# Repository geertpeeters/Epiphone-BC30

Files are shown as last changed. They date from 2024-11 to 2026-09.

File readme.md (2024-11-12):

# Epiphone Blues Custom 30 modifications

## A compact guideline

## Version history

| Version Nr | Version Date | Modification |
|---|---|---|
| 1.0.0 | 2020-01-06 | Initial version for external distribution |

Table 1. Version History

# Introduction

## 1. General feature set

- Ampplifier with an "all tube" signal path
- Tube rectifier
- Two distinct channels
- 3 way equalizer
- Overdrive channel mid control
- Independent and interactive EQ mode
- Tube powered and transformer driven reverb
- 30W class AB (pentode) mode
- 15W Class A (triode) mode
- Multiple speaker output jacks (2x4 Ohm, 2x8 Ohm, 1x16 Ohm)
- "Lady Luck" speakers specially designed for this amplifier

## 2. Overall desired improvements

- Overall "harsh" clean and overdriven sounds
- Perceived as "too bright" with lack of bottom end
- Not switchable between clean and overdriven channel without tweaking
  the EQ settings

## 3. Dismantling instructions

To remove the chassis do the following

1.  Remove the mains power cable
2.  Remove the guitar cable from the input
3.  Remove the speaker cable from the output
4.  Remove the reverb RCA cables from the underside of the chassis
5.  Pry off the 4 plastic covers on top of the amp with a small flat
    blade screwdriver
6.  Remove the machine screws with a \#2 phillips screwdriver
7.  Grab the HT and OT and gently pull out while lifting up
8.  Connect one lead of an alligator clip to the chassis, and the other
    end to the common of a multimeter. probe the power tube solder
    joints making sure to leave one hand in your pocket and confirm the
    meter reads 0V

## 4. Affected components

### 4.1. Capacitors

| Component | Identification | Actual Value | Modification | Expected result |
|---|---|---|---|---|
| **C3** | 471/1kV | 470pF/1000V  | Unsolder or cut off | |
| **C4** | 101/1kV | 100pF/1000V  | Unsolder or cut off | |
| **C5** | 471/400V | 470pF/400V | Unsolder or cut off | |
| **C6** | 101/1kV | 100pF/1000V  | Unsolder or cut off | |
| **C10** | 471/1kV | 470pF/1000V  | Unsolder or cut off | |
| **C15** | 22µF/35V | | Replace 2.2µF/35V | |
| **C16** | 471/1kV | 470pF/1000V  | Increase to 680pF : put 220pF in parallel | |

### 4.2. Resistors

| Component | Identification | Modification | Expected result |
|---|---|---|---|
| **R3** | 2.2kΩ/1W | Replace 1kΩ/1W or shunt with 2.2kΩ for 1.1kΩ | |
| **R5** | 1MΩ/1W | Shunt with 820kΩ for 450kΩ | |
| **R6** | 1MΩ/1W | Shunt with 820k for 450kΩ | |
| **R8** | 2.2kΩ/1W | Replace 1kΩ/1W or shunt with 2.2kΩ for 1.1kΩ | |
| **R15** | 2.2kΩ/1W | Replace 1.6kΩ/1W or shunt with 5.6kΩ for 1.58kΩ | |
| **R21** | 2.2kΩ/1W | Replace 1kΩ/1W or shunt with 2.2kΩ for 1.1kΩ | |
| **R23** | 10kΩ/1W | Replace 5.6kΩ/1W or shunt with 12kΩ for 5.45kΩ | |
| **R39** | 220kΩ/1W | Replace 1MΩ linear potentiometer | |
| **R52**\* | 68Ω/25W | Put in between 350V line and PCB. Mount against chassis for cooling | |
| **R53**\* | 68Ω/25W | Put in between 350V line and PCB. Mount against chassis for cooling | |

## 5. Detailed findings

### 5.1. Capacitors

#### 5.1.1. C3

- **Stock value**: 470pF/1000V
- **Action**: unsolder or cut off
- **Affects**: Clean channel
- **Perceived result**:
  - Cuts brightness off
  - Clean channel sounds less treble-y. easier to manage

#### 5.1.2. C4

- **Stock value**: 470pF/1000V
- **Action**: unsolder or cut off
- **Affects**: Clean channel
- **Perceived result**: Cuts brightness off

#### 5.1.3. C5

- **Stock value**: 470pF/400V
- **Action**: unsolder or cut off
- **Affects**: Both channels. Cuts brightness off
- **Perceived result**:

#### 5.1.4. C6

- **Stock value**: 100pF/1000V
- **Action**: unsolder or cut off
- **Affects**: Both channels. Cuts brightness off
- **Perceived result**: Drive channel now sounds more like a fizzy
  distortion rather than a crunchy overdrive

#### 5.1.5. C10

- **Stock value**: 470pF/1000V
- **Action**: unsolder or cut off
- **Affects**: Both channels. Cuts brightness off
- **Perceived result**: lost way too much top end

##### C15

- **Stock value**: 22uF/35V
- **Action**: replace 2.2uF/35V
- **Affects**: overdrive channel
- **Perceived result**: makes the whole amp brighter, less bottom end.

#### 5.1.6. C16

- **Stock value**: 470pF/1000V
- **Action**: increase to 680pF, put capacitor in parallel
- **Affects**:
- **Perceived result**:

### 5.2. Resistors

#### 5.2.1. R3

- **Stock value**: 2.2kΩ/1W
- **Action**: replace 1k/1W
- **Affects**: ?
- **Perceived result**:?

#### 5.2.2. R5

- **Stock value**: 1MΩ/1W
- **Action**: shunt with 820kΩ/1W
- **Affects**: Drive channel
- **Perceived result**:
  - The fundamental pass frequency is halved
  - Potential divider is halved (more signal to next stage)
  - The sound opens up with increased bass but no loss of top end, not
    dark and not harsh

#### 5.2.3. R6

- **Stock value**: 1MΩ/1W
- **Action**: shunt with 820kΩ/1W
- **Affects**: Drive channel
- **Perceived result**:
  - The fundamental pass frequency is halved
  - Potential divider is halved (more signal to next stage)
  - The sound opens up with increased bass but no loss of top end, not
    dark and not harsh

#### 5.2.4. R8

- **Stock value**: 2.2kΩ/1W
- **Action**: replace 1kΩ/1W
- **Affects**: Drive channel
- **Perceived result**: ?

#### 5.2.5. R15

- **Stock value**: 2.2kΩ/1W
- **Action**: replace 1.6kΩ/1W
- **Affects**: Drive channel
- **Perceived result**:
  - Smoother overdrive : affects overdrive channel
  - Lowered gain → ???
  - Distortion is a bit smoother and not so harsh
  - Really mellows out the channel drive
  - The drive is more manageable
  - Is the best sounding, most noticeable among the mods mentioned.
  - Unbelievable difference. That gain boost brought some fire into the
    tone. Gain was nicely saturated & balanced.

#### 5.2.6. R23

- **Stock value**: 10kΩ/1W
- **Action**: replace 5.6kΩ/1W
- **Affects**: ?
- **Perceived result**: ?

#### 5.2.7. R39

- **Stock value**: 220kΩ/1W
- **Action**:
  - Replace by 1MΩ potentiometer
  - Place potentiometer in front panel of the chassis
  - Wire to PCB with shielded signal cable
- **Affects**: Volume control improvement of clean channel
- **Perceived result**:
  - Better control of clean channel volume
  - Clean channel can be cranked up and controlled by master volume knob

#### 5.2.8. R52
- **Stock value**: not existing
- **Action**:
  - Put in between 350V AC lead of transformer and SS2 on the PCB
- **Affects**: Protects against transformer blow-up
- **Perceived result**: None. Increases robustness of amplifier

#### 5.2.9. R53

- **Stock value**: not existing
- **Action**:
  - Put in between 350V AC lead of transformer and SS1 on the PCB
- **Affects**: Protects against transformer blow-up
- **Perceived result**: None. Increases robustness of amplifier

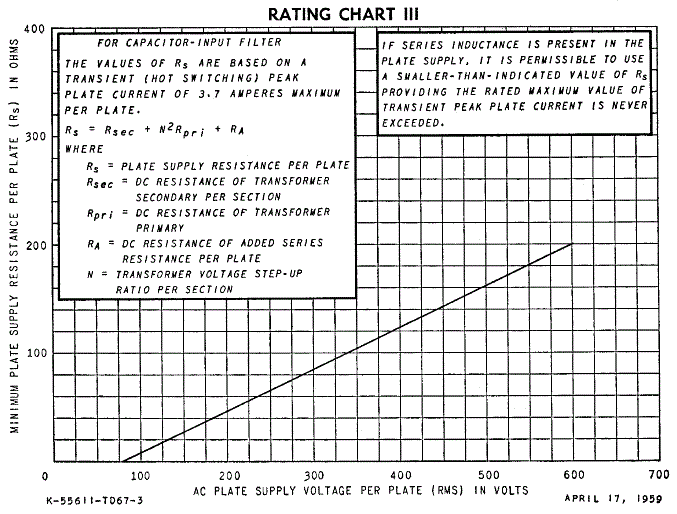
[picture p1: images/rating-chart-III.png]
rating chart III


Figure 1. Limiting resistance calculation graph

It is worth noting that the choke will slightly lower the required
limiting resistance, but not by much. The above datasheet chart provides
the calculation necessary to determine the limiting resistance provided
by the transformer:

Rs = Rsec + N2Rpri

measured Rpri is 5.5R and Rsec is 37.5R (75R for the entire winding) so…
Transformer ratio N = 350 / 240 = 1.45 so…

37.5 + (1.45 \* 1.45 \* 5.5) = 49R

The chart shows that for a 350V tap, the limiting resistance needs to be
around 105R for EACH PLATE of the rectifier, and this is for a fresh
valve manufactured to 1959 standards. So lets assume 115R will be safer
for modern 5AR4s,

115R - 49R = 66R

68R is the nearest standard resistor, two of these should be chassis
mounted inside the amp, and the transformer secondary taps (350V) should
be wired directly to these and then the other ends of the resistors
wired to the PCB. 25W types are recommended, as the voltage rating
should be in the region of 550V. The working voltage in practice will be
much much lower than this but at the moment of power on, it will be
higher and it’s nice to know that nothing can go wrong!

BTW, using the standby switch makes the problem worse because the
rectifier is fully ready to conduct. If you are unlucky enough to flip
the switch at the moment the mains AC voltage is at it’s peak then
destruction is almost guaranteed. Starting the amp from cold (without
the standby) will slightly reduce the likelihood of failure. So, for a
happy BC30, don’t use the standby and install limiting resistors!

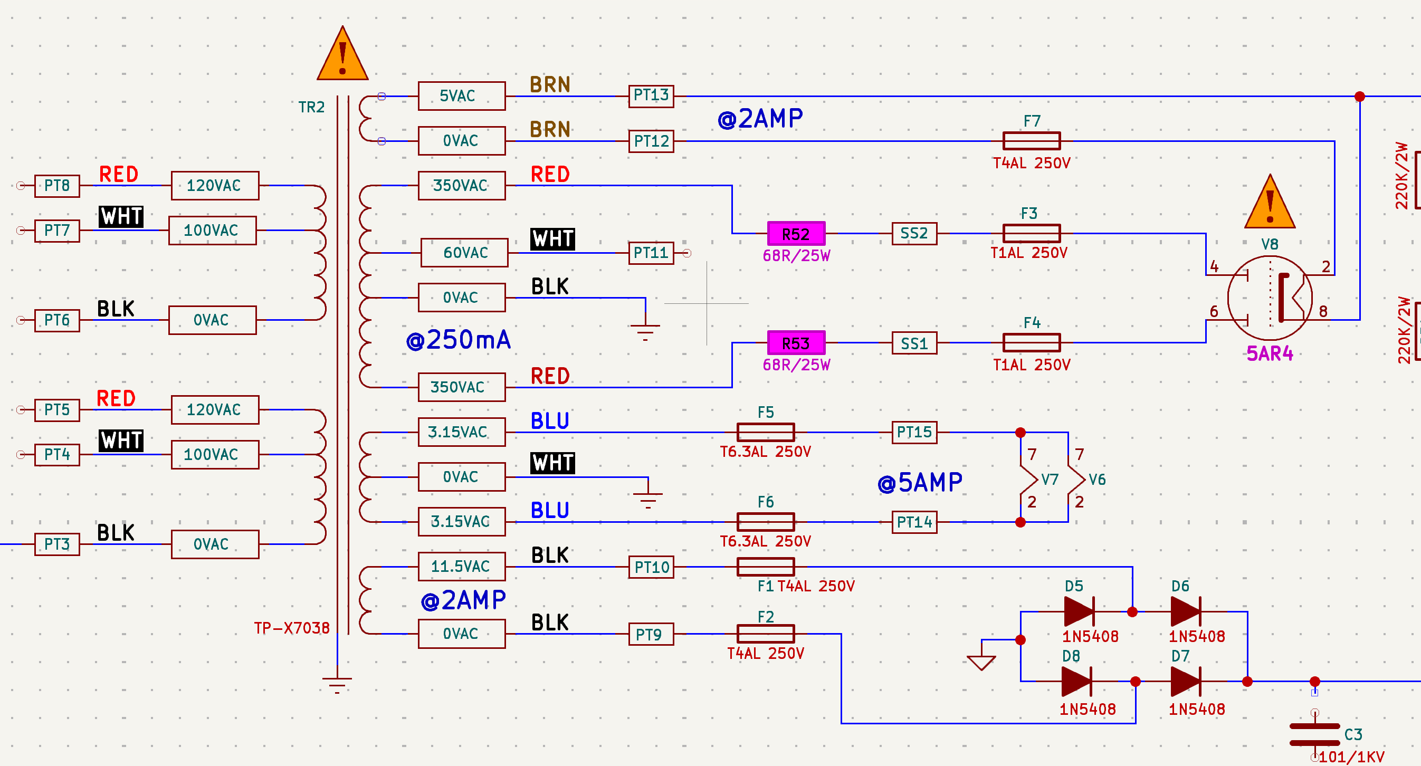
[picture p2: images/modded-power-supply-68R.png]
modded power supply 68R

Figure 2. Limiting resistors of 68Ω

### 5.3. Tried out combinations and their findings

<table>
<td class="content">C5,C6,C10,R15<br />
<strong>This amp is singing now<br />
</strong> Much more manageable/tweak-able</td>
</table>

<table>
<td class="content">C3,C5,C6,R15<br />
In that order you’ll hear the difference</td>
</table>

<table>
<td class="content">C3,C5,C6,C15,R15,R21<br />
<strong>These mods really open this amp up<br />
</strong> EQ is way more definable between active and not<br />
** More use out of the mid channel</td>
</table>

<table>
<td class="content">C3,C5,C6,R15,R21,C15<br />
<strong>The thing now sounds great<br />
</strong> EQ is extremely effective and sensitive<br />
<strong>Has more gain but it is by no means a 'high gain' amp<br />
</strong> Bigger sound and more responsive to touch<br />
</td>
</table>

### 5.4. Other modifications

#### 5.4.1. Remove standby switch SW4

- Use the whole for master volume mod

#### 5.4.2. "Fat Gain" switch

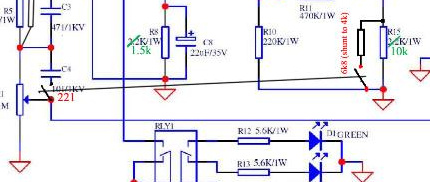
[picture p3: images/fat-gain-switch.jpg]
fat gain switch


Figure 3. Fat gain switch

- Use a DPDT (Double Pole, Double Throw) switch

#### 5.4.3. Other recommendations

- Tidy all wirings
- Re-valve Rectifier replacement

#### 5.4.4. Pre-amp Tube recommendations

- Ei ECC83
- RCA
- Mullard
- Telefunken
- JJ ECC83

- **V1, V2**: Harma ECC83 Retro (Mullard rebuild)
- **V3, V5**: (reverb) Stock EH so far

#### 5.4.5. Phase inverter recommendations

- **V4**: (PI) Harma ECC83 Retro - balanced

#### 5.4.6. Output valve recommendations

- Tungsol 5881
- Svetlana 6L6
- JJ Electronic 5881
- Groove Tube 5881
- NOS Philips JAN 6L6WGB/5881
- Svetlana=C= 6L6GC

#### 5.4.7. Reverb drive valve recommendations

- Sovtek 5AR4

### 5.5. Other hardware

#### 5.5.1. Output transformer and choke

- Mercury Magnetics is selling a replacement output transformer and
  choke

## 6. Links

- [Mercury
  Magnetics](https://www.mercurymagnetics.com/products/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)

- [Switch types](https://en.wikipedia.org/wiki/Switch)

- [forum
  discussion](https://www.tdpri.com/threads/anyone-try-the-new-epiphone-blues-custom.54114/)

Last updated 2020-01-06 20:42:20 +0100

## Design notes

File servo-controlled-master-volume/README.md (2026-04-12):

# Servo Controlled Master Volume
### Beschrijving & Functie
* Deze controller fungeert als de mechanische interface tussen de Boss GT-5 expressiepedaal en de fysieke master volume van een Epiphone Custom Blues 30 versterker.
* Het systeem vertaalt in de MIDI-modus inkomende Control Change data naar nauwkeurige hoekverdraaiingen van een servo-motor die de potmeter op de versterker fysiek bedient.
* Via een centrale microprocessor wordt continu gecontroleerd of de gebruiker de voorkeur geeft aan externe MIDI-automatisering of aan de lokale manuele modus via de ingebouwde potmeter.
* De gebruiker kan met een modusschakelaar direct wisselen tussen deze twee operationele standen om de gewenste bron van controle te bepalen.
* De programmeerbare instelmodus maakt het mogelijk om met een enkele drukknop de kritieke fysieke stop-punten van de servo-motor nauwkeurig te kalibreren voor de specifieke potmeter-range.
* Tijdens dit proces worden de ondergrens en bovengrens via een sequentiële klik-methode gedefinieerd, waarbij een status-LED met specifieke flitspatronen de bevestiging van elke stap weergeeft.
* Alle gekalibreerde parameters worden direct weggeschreven naar het EEPROM-geheugen van de Arduino, waardoor de fysieke grenswaarden na een stroomonderbreking onmiddellijk weer actief zijn.
* Deze hybride opzet garandeert dat de analoge buizenversterker kan profiteren van moderne digitale expressie-controle zonder dat de interne circuits elektrisch gemodificeerd hoeven te worden.
* Door de mechanische koppeling tussen de servo en de master volume potmeter blijft de integriteit van het audiosignaal volledig behouden terwijl de dynamische controle over de output toeneemt.
* De controller zorgt hiermee voor een naadloze integratie van vintage versterkertechniek met de precisie van moderne MIDI-gestuurde effectenbakken en pedalen.



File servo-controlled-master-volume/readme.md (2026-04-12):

# servo-controlled-master-volume
Control the master volume of a guitar amp with a servo  listening to midi CC messages

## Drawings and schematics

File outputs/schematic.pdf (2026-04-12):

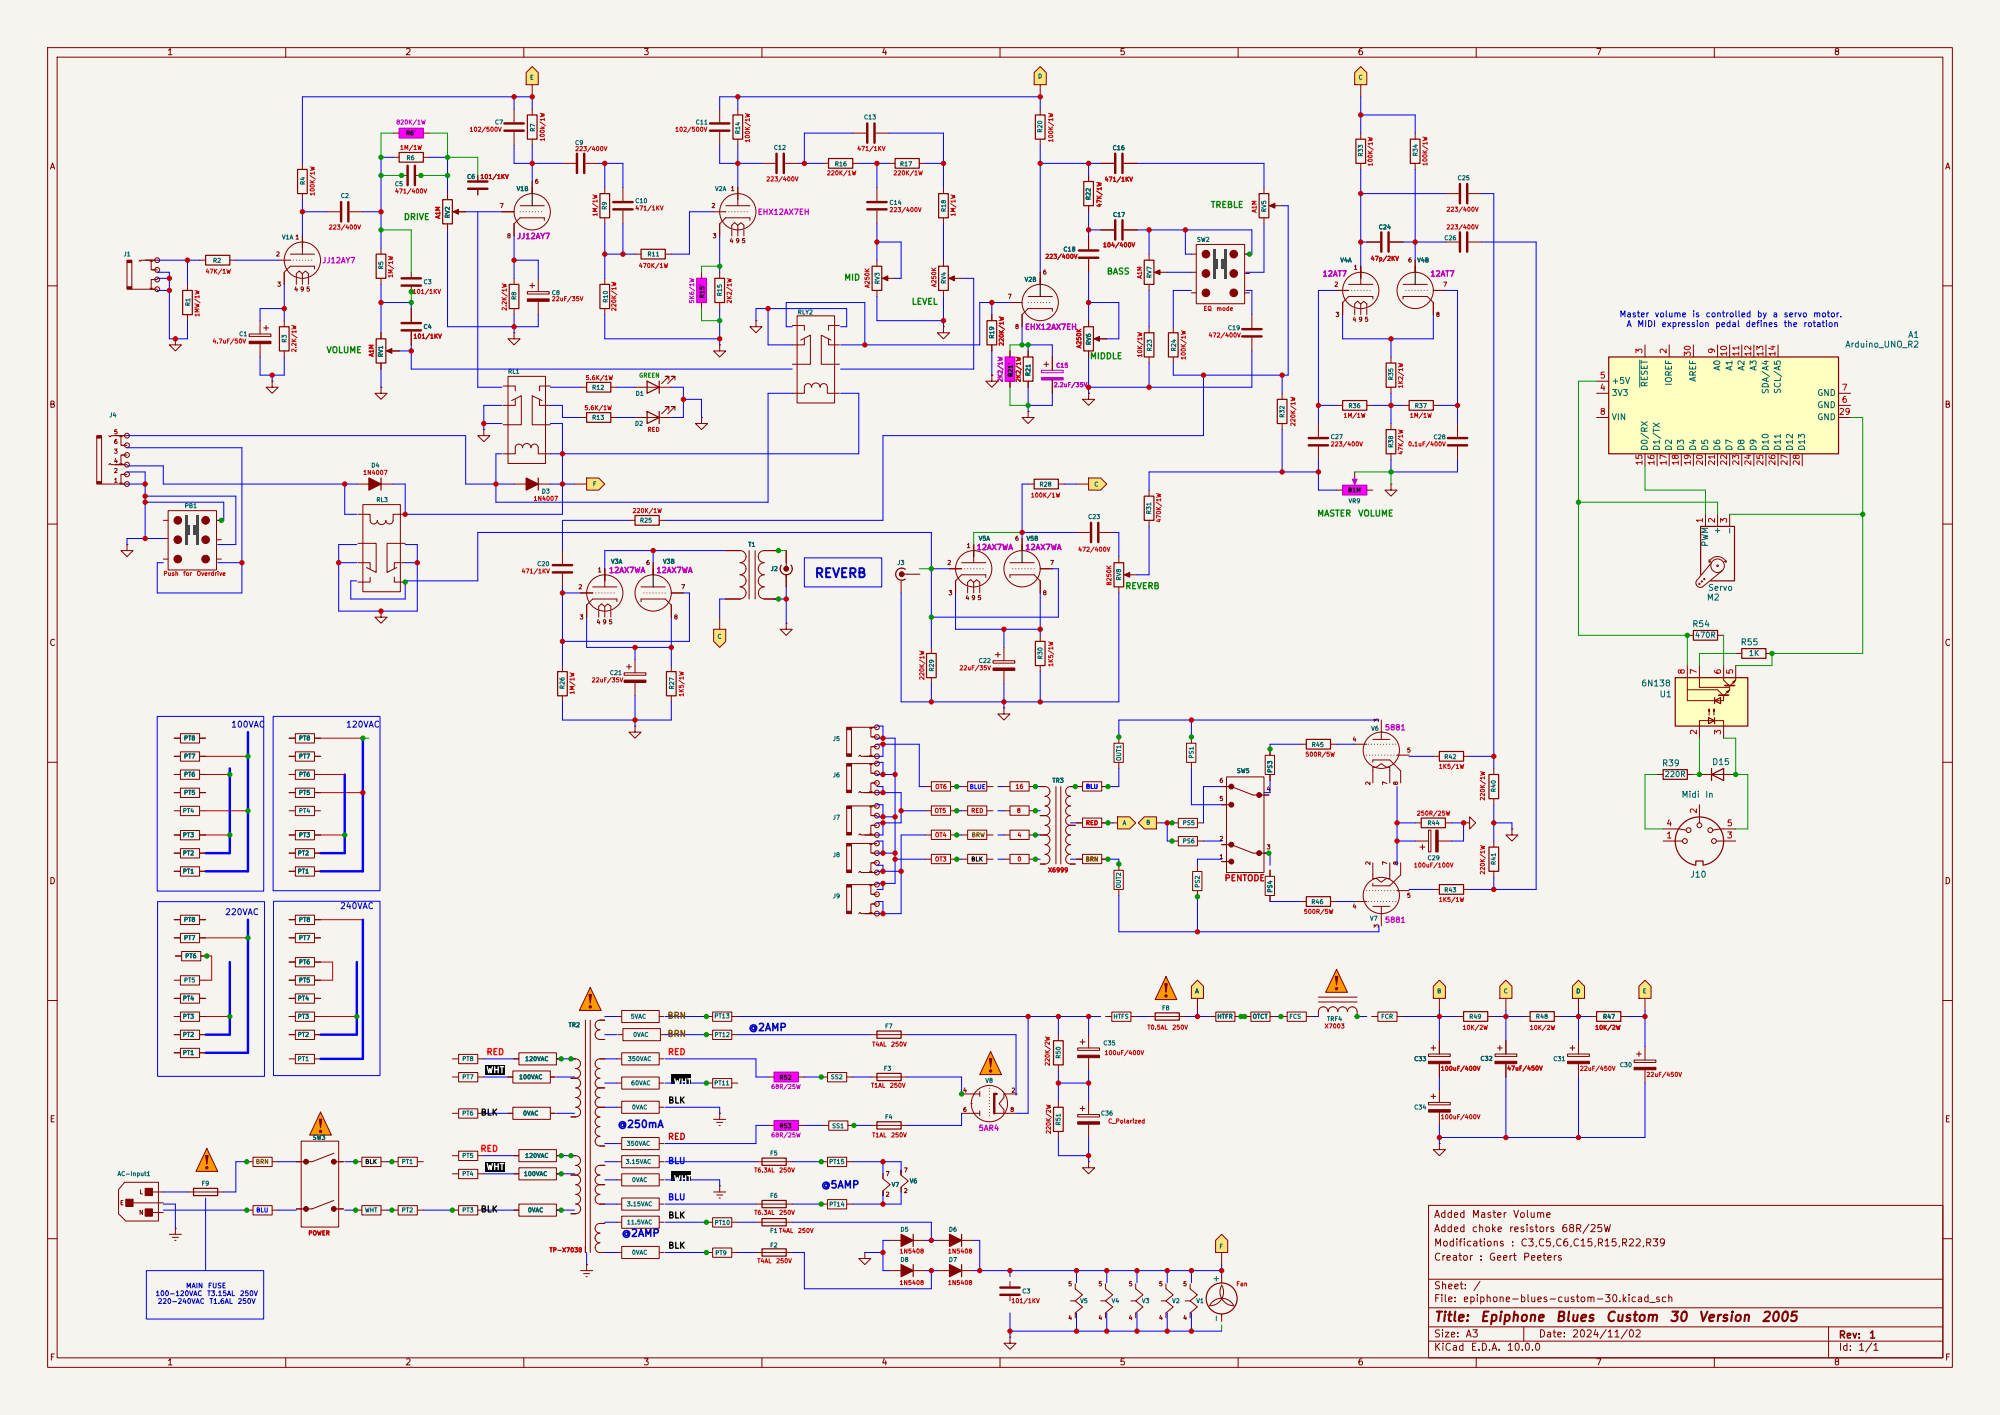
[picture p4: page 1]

Master volume is controlled by a servo motor.
A MIDI expression pedal defines the rotation

9 A1 10 A2 11 A3 12 SDA/A4 13 SCL/A5 14 D0/RX 15 D1/TX 16 D2 17 D3 18 D4 19 D5 20 D6 21 D7 22 D8 23 D9 24 D10 25 D11 26 D12 27 D13 28 GND

Added Master Volume
Added choke resistors 68R/25W
Creator : Geert Peeters Modifications : C3,C5,C6,C15,R15,R22,R39

File: epiphone-blues-custom-30.kicad_sch
Title: Epiphone Blues Custom 30 Version 2005

Size: A3 | Rev: 1 | F Date: 2024/11/02
KiCad E.D.A. 10.0.0 | Id: 1/1

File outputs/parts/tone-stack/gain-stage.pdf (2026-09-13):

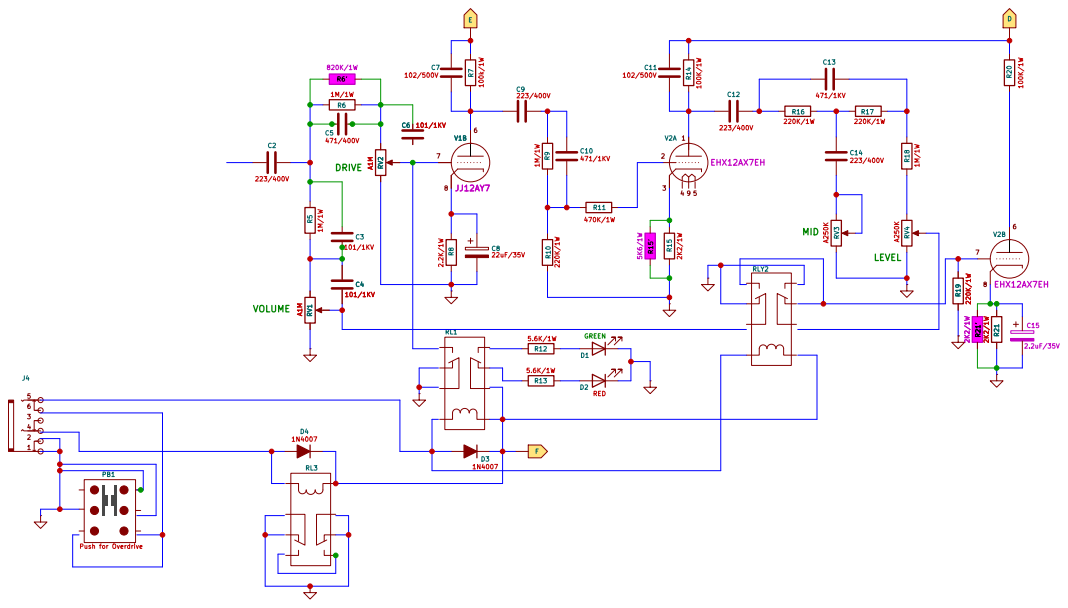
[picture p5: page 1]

Sheet: /
File: gain-stage.kicad_sch
Title: Epiphone Blues Custom 30 Version 2005

Size: A3 | Rev: 1 | F Date: 2024/11/02
KiCad E.D.A. 10.0.6 | Id: 1/1

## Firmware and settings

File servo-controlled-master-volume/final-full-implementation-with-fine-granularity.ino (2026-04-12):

#include <Servo.h>  // Include the Servo library
#include <EEPROM.h> // Include the EEPROM library for non-volatile storage
#include <MIDI.h>   // Include the MIDI Library from Forty Seven Effects

// --- Pin Definitions ---
const int POT_PIN = A0;   // Analog pin for potentiometer
const int SERVO_PIN = 9;  // Digital pin for servo control
const int BUTTON_PIN = 2; // Digital pin for the push button (using INPUT_PULLUP)

// Single LED Pin - IMPORTANT: Connect a resistor (e.g., 220-330 Ohm) in series!
const int LED_PIN = 8; // Using digital pin 8 for the single LED
const int MODE_SWITCH_PIN = 4; // Digital pin for the mode toggle switch (using INPUT_PULLUP)

// --- Constants for Mode and Button ---
const long LONG_PRESS_DURATION = 2000; // 2 seconds for a long press

// --- YOUR POTENTIOMETER'S USABLE ELECTRICAL RANGE ---
// Based on your last successful test, these should map correctly now.
// If you still experience dead zones, re-run the previous test to find exact values.
const int CUSTOM_POT_MIN = 0;
const int CUSTOM_POT_MAX = 1023;

// --- YOUR CALIBRATED WIDE-ANGLE SERVO RANGES ---
// These are the values you determined from calibration:
const int SERVO_MIN_PULSE_US = 845;   // Your calibrated minimum pulse width
const int SERVO_MAX_PULSE_US = 2160;  // Your calibrated maximum pulse width
const int SERVO_ACTUAL_MIN_ANGLE = 0;   // Assuming your lowest pulse width maps to 0 degrees
const int SERVO_ACTUAL_MAX_ANGLE = 225; // Your observed total movement (180 + 45 = 225 degrees)


// --- LED Blinking Pattern Durations (milliseconds) ---
// For NORMAL_MODE: Very slow blink to indicate active manual control
const long NORMAL_MODE_ON_TIME = 50;
const long NORMAL_MODE_OFF_TIME = 1950; // Total 2 second cycle for Normal Mode

// For SET_LOW_MODE: Short ON, Long OFF
const long LOW_MODE_ON_TIME = 100;
const long LOW_MODE_OFF_TIME = 900;

// For SET_HIGH_MODE: Short ON, Shorter OFF
const long HIGH_MODE_ON_TIME = 100;
const long HIGH_MODE_OFF_TIME = 400;

// For STORE_FEEDBACK: Very rapid flashing after saving
const long STORE_FEEDBACK_TOGGLE_TIME = 50; // ON and OFF duration for rapid flash
const unsigned long STORE_FEEDBACK_DURATION = 500; // Total duration of the rapid flash

// For momentary button press feedback
const long MOMENTARY_FLASH_DURATION = 30; // Very brief flash for button feedback


// --- MIDI Constants ---
const byte MIDI_CHANNEL = 1;    // MIDI Channel to listen on (0-15, but usually 1-16. Library uses 0-15)
const byte MIDI_CC_NUMBER = 7;  // Control Change Number for Main Volume

// --- Forward declaration for LedIndicator (needed because PushButton uses it) ---
class LedIndicator;

// --- 1. ServoController Class ---
// This class handles controlling the servo based on mapped angles and uses writeMicroseconds.
class ServoController {
public:
  // _minAngle and _maxAngle here define the *desired output angle range* for the servo (e.g., 0-225)
  ServoController(int pin, int minAngle, int maxAngle)
    : _pin(pin), _minAngle(minAngle), _maxAngle(maxAngle) {}
    
  void attach(int initialPotValue, int potMin, int potMax) {
    // Attach the servo using the calibrated pulse widths.
    // This tells the Servo library the true electrical limits of your servo.
    _servo.attach(_pin, SERVO_MIN_PULSE_US, SERVO_MAX_PULSE_US);
    // Set initial position based on current pot value
    writeMappedAngle(initialPotValue, potMin, potMax);
  }

  void writeMappedAngle(int potValue, int potMin, int potMax) {
    // Map the potentiometer's input range to the servo's desired angle range
    int targetAngle = map(potValue, potMin, potMax, _minAngle, _maxAngle);
    // Constrain the target angle to ensure it stays within the defined physical limits
    targetAngle = constrain(targetAngle, _minAngle, _maxAngle);
    
    // Convert the target angle to a pulse width using the calibrated pulse range.
    // This is crucial for wide-angle servos, as Servo.write(angle) might internally
    // constrain to 0-180 degrees. By doing this mapping explicitly, we ensure
    // 0-225 degrees truly maps to 845-2160us.
    long commandedPulseWidth = map(targetAngle, _minAngle, _maxAngle, SERVO_MIN_PULSE_US, SERVO_MAX_PULSE_US);
    
    // Constrain the pulse width to the known valid range (just in case of mapping edge cases)
    commandedPulseWidth = constrain(commandedPulseWidth, SERVO_MIN_PULSE_US, SERVO_MAX_PULSE_US);
    
    _servo.writeMicroseconds(commandedPulseWidth); // Command the servo directly with microseconds
    _currentAngle = targetAngle; // Store the current angle for getCurrentAngle()
  }

  void writeAngle(int angle) {
    // Constrain the input angle to the servo's defined physical range
    int constrainedAngle = constrain(angle, _minAngle, _maxAngle);
    
    // Convert the constrained angle to a pulse width
    long commandedPulseWidth = map(constrainedAngle, _minAngle, _maxAngle, SERVO_MIN_PULSE_US, SERVO_MAX_PULSE_US);
    commandedPulseWidth = constrain(commandedPulseWidth, SERVO_MIN_PULSE_US, SERVO_MAX_PULSE_US);
    
    _servo.writeMicroseconds(commandedPulseWidth); // Command the servo directly
    _currentAngle = constrainedAngle; // Store the current angle
  }

  int getCurrentAngle() const { return _currentAngle; }
private:
  Servo _servo;
  int _pin;
  int _minAngle;
  int _maxAngle;
  int _currentAngle; // Stores the last commanded angle
};

// --- 4. LedIndicator Class ---
// Manages the blinking patterns and state of a single LED.
class LedIndicator {
public:
  LedIndicator(int pin)
    : _ledPin(pin), _blinkingActive(false), _onDuration(0), _offDuration(0),
      _lastToggleTime(0), _ledState(LOW), _feedbackBlinkActive(false), _feedbackStartTime(0),
      _momentaryFlashActive(false), _momentaryFlashStartTime(0) { // Initialize new members
    pinMode(_ledPin, OUTPUT);
    digitalWrite(_ledPin, LOW); // Ensure LED is off initially
  }

  // Turns the LED completely off (e.g., for MIDI mode)
  void turnOff() {
    _blinkingActive = false;
    _feedbackBlinkActive = false;
    _momentaryFlashActive = false; // Ensure momentary flash is also off
    digitalWrite(_ledPin, LOW);
  }

  // Sets a continuous blinking pattern for modes (e.g., slow blink for SET_LOW_MODE)
  void setBlinkPattern(long onDuration, long offDuration) {
    _blinkingActive = true;
    _feedbackBlinkActive = false; // Stop any ongoing feedback blink
    _momentaryFlashActive = false; // Stop any ongoing momentary flash
    _onDuration = onDuration;
    _offDuration = offDuration;
    _lastToggleTime = millis(); // Reset timer to start new pattern immediately
    _ledState = HIGH;           // Start new pattern with LED ON
    digitalWrite(_ledPin, HIGH);
  }

  // Starts a rapid, short-duration blink for feedback (e.g., after storing a position)
  void startFeedbackBlink() {
    _blinkingActive = false;    // Stop any mode blinking
    _momentaryFlashActive = false; // Stop any momentary flashes
    _feedbackBlinkActive = true;
    _feedbackStartTime = millis(); // Record when the feedback blink started
    _lastToggleTime = millis();    // Initialize for immediate first toggle
    _ledState = HIGH;              // Force first state ON
    digitalWrite(_ledPin, HIGH);
  }

  // Starts a very brief, high-priority flash for button press confirmation
  void startMomentaryFlash() {
    _momentaryFlashActive = true;
    _momentaryFlashStartTime = millis();
    digitalWrite(_ledPin, HIGH); // Turn on immediately
  }

  // New public method to check if a specific blink pattern is currently active
  bool isCurrentPattern(long onDuration, long offDuration) const {
    return _blinkingActive && (_onDuration == onDuration) && (_offDuration == offDuration);
  }

  // This function must be called repeatedly in loop() to update the LED's state
  void update() {
    // Priority 1: Momentary flash (for button presses)
    if (_momentaryFlashActive) {
      if (millis() - _momentaryFlashStartTime >= MOMENTARY_FLASH_DURATION) {
        digitalWrite(_ledPin, LOW);
        _momentaryFlashActive = false;
        // Reset _lastToggleTime to ensure the underlying mode's blink pattern
        // restarts correctly after the momentary flash ends.
        _lastToggleTime = millis(); 
      }
      return; // Do not process other blinking modes if momentary flash is active
    }

    // Priority 2: Feedback blink (after storing positions)
    if (_feedbackBlinkActive) {
      // Manage the rapid flashing for the defined feedback duration
      if (millis() - _feedbackStartTime >= STORE_FEEDBACK_DURATION) {
        _feedbackBlinkActive = false; // Stop feedback blink after duration
        digitalWrite(_ledPin, LOW);   // Ensure LED is OFF after feedback
      } else {
        // Continue rapid flashing
        if (millis() - _lastToggleTime >= STORE_FEEDBACK_TOGGLE_TIME) {
          _ledState = !_ledState; // Toggle LED state (ON to OFF, or OFF to ON)
          digitalWrite(_ledPin, _ledState ? HIGH : LOW);
          _lastToggleTime = millis(); // Update last toggle time
        }
      }
    } 
    // Priority 3: Regular mode blink pattern
    else if (_blinkingActive) {
      // Manage the current mode's regular blink pattern
      if (_ledState == HIGH) { // If LED is currently ON
        if (millis() - _lastToggleTime >= _onDuration) {
          digitalWrite(_ledPin, LOW); // Turn OFF
          _ledState = LOW;
          _lastToggleTime = millis();
        }
      } else { // If LED is currently OFF
        if (millis() - _lastToggleTime >= _offDuration) {
          digitalWrite(_ledPin, HIGH); // Turn ON
          _ledState = HIGH;
          _lastToggleTime = millis();
        }
      }
    } else {
      // If no blinking is active (e.g., in MIDI_CONTROL_MODE after a momentary flash,
      // or if explicitly turned off), ensure LED is off.
      digitalWrite(_ledPin, LOW);
    }
  }

private:
  int _ledPin;
  bool _blinkingActive;     // True if a regular mode blink pattern is active
  long _onDuration;         // ON time for regular blink pattern
  long _offDuration;        // OFF time for regular blink pattern
  unsigned long _lastToggleTime; // Last time the LED state was changed
  bool _ledState;           // Current state of the LED (HIGH/LOW)

  bool _feedbackBlinkActive;    // True if feedback blink is active
  unsigned long _feedbackStartTime; // When the feedback blink started

  bool _momentaryFlashActive;      // True if a momentary flash is active
  unsigned long _momentaryFlashStartTime; // When the momentary flash started
};

// --- 2. PushButton Class ---
// Handles debouncing and detecting short/long presses for the button.
class PushButton {
public:
  // Constructor now takes a reference to the LedIndicator object
  PushButton(int pin, long longPressDuration, LedIndicator& led) 
    : _pin(pin), _longPressDuration(longPressDuration),
      _lastButtonState(HIGH), _buttonPressStartTime(0), _longPressActive(false),
      _shortPressTriggered(false), _led(led) // Initialize the LedIndicator reference
  {
    pinMode(_pin, INPUT_PULLUP); // Use internal pull-up resistor
  }
  void update() {
    int currentButtonState = digitalRead(_pin);

    // Detect change in button state
    if (currentButtonState != _lastButtonState) {
      _lastButtonStateChangeTime = millis();
    }

    // Debounce logic
    if ((millis() - _lastButtonStateChangeTime) > _debounceDelay) {
      if (currentButtonState != _debouncedButtonState) {
        _debouncedButtonState = currentButtonState;

        if (_debouncedButtonState == LOW) { // Button just pressed down
          _buttonPressStartTime = millis();
          _longPressActive = false;
          _shortPressTriggered = false; // Reset short press flag
        } else { // Button just released
          unsigned long pressDuration = millis() - _buttonPressStartTime;
          if (pressDuration >= _debounceDelay && pressDuration < _longPressDuration) {
            _shortPressTriggered = true; // Mark short press if duration is within range
          }
          _longPressActive = false; // Reset long press flag
        }
      }
    }
    _lastButtonState = currentButtonState;

    // Check for ongoing long press (button held down past duration)
    if (_debouncedButtonState == LOW &&
        (millis() - _buttonPressStartTime >= _longPressDuration) &&
        !_longPressActive) {
      _longPressActive = true; // Mark long press as active
    }
  }

  // Returns true once if a long press was just completed
  bool isLongPressTriggered() {
    if (_longPressActive) {
      _longPressActive = false; // Consume the event
      _led.startMomentaryFlash(); // Provide visual feedback for long press
      return true;
    }
    return false;
  }

  // Returns true once if a short press was just completed
  bool isShortPressTriggered() {
    if (_shortPressTriggered) {
      _shortPressTriggered = false; // Consume the event
      _led.startMomentaryFlash(); // Provide visual feedback for short press
      return true;
    }
    return false;
  }
private:
  int _pin;
  long _longPressDuration;
  int _lastButtonState;
  unsigned long _buttonPressStartTime;
  bool _longPressActive;
  bool _shortPressTriggered;
  int _debouncedButtonState = HIGH;
  unsigned long _lastButtonStateChangeTime = 0;
  const long _debounceDelay = 50; // Standard debounce delay
  LedIndicator& _led; // Reference to the LED indicator object
};
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
void loop() {
  // Always update store button state
  storeButton.update();
  
  // Continuously read MIDI messages. This is crucial for MIDI control.
  // This non-blocking call processes any incoming MIDI data.
  MIDI.read(); 

  // --- Handle Main Mode Toggle Switch ---
  // Read the current state of the physical toggle switch
  int currentModeSwitchState = digitalRead(MODE_SWITCH_PIN);

  // Debounce the toggle switch to prevent false readings
  if (currentModeSwitchState != lastModeSwitchState) {
    lastModeSwitchChangeTime = millis(); // Record time of state change
  }

  // After debounce delay, check if the debounced state is actually different
  // and trigger a mode change if necessary.
  if ((millis() - lastModeSwitchChangeTime) > MODE_SWITCH_DEBOUNCE_DELAY) {
    // If the switch is LOW and we are in Potentiometer Control Mode, switch to MIDI Control
    if (currentModeSwitchState == LOW && currentMainMode == MANUAL_POT_CONTROL_MODE) {
      currentMainMode = MIDI_CONTROL_MODE;
      ledIndicator.turnOff(); // Ensure LED is off in MIDI mode
      // Serial.println("Switched to MIDI_CONTROL_MODE. Servo now controlled by MIDI CC#7."); // Removed Serial.print
    } 
    // If the switch is HIGH and we are in MIDI Control Mode, switch back to Potentiometer Control
    else if (currentModeSwitchState == HIGH && currentMainMode == MIDI_CONTROL_MODE) {
      currentMainMode = MANUAL_POT_CONTROL_MODE;
      // When returning to manual mode, set LED to NORMAL_MODE pattern
      currentManualMode = NORMAL_MODE; // Ensure sub-mode is also reset to normal
      ledIndicator.setBlinkPattern(NORMAL_MODE_ON_TIME, NORMAL_MODE_OFF_TIME); 
      // Serial.println("Switched to MANUAL_POT_CONTROL_MODE. Servo now controlled by Potentiometer."); // Removed Serial.print
      // Re-sync servo to current potentiometer position immediately (NO SMOOTHING)
      int rawPotValue = analogRead(POT_PIN);
      servoCtrl.writeMappedAngle(rawPotValue, CUSTOM_POT_MIN, CUSTOM_POT_MAX);
    }
  }
  lastModeSwitchState = currentModeSwitchState; // Update last state for next iteration


  // --- Main Control Mode Logic ---
  switch (currentMainMode) {
    case MANUAL_POT_CONTROL_MODE:
      // In this mode, the potentiometer controls the servo.
      // The button (D2) is used to enter/exit calibration sub-modes (SET_LOW/HIGH).
      
      // Read raw potentiometer value directly (NO SMOOTHING)
      int rawPotValue = analogRead(POT_PIN);
      
      // Map pot range to the servo's actual angle range
      servoCtrl.writeMappedAngle(rawPotValue, CUSTOM_POT_MIN, CUSTOM_POT_MAX);

      // No Serial.print for pot/servo values here to avoid D0/RX conflict.

      // --- Mode State Machine (Your original SystemMode logic for setting limits) ---
      switch (currentManualMode) {
        case NORMAL_MODE:
          // Ensure LED shows the Normal Mode blink pattern if no other blink is active
          if (!ledIndicator.isCurrentPattern(NORMAL_MODE_ON_TIME, NORMAL_MODE_OFF_TIME)) {
              ledIndicator.setBlinkPattern(NORMAL_MODE_ON_TIME, NORMAL_MODE_OFF_TIME);
          }

          // In Normal Mode, short press transitions to SET_LOW_MODE for calibration.
          if (storeButton.isShortPressTriggered()) {
            currentManualMode = SET_LOW_MODE;
            ledIndicator.setBlinkPattern(LOW_MODE_ON_TIME, LOW_MODE_OFF_TIME); // Low Mode blink pattern
            // Serial.println("\n--- Entering SET_LOW_MODE: Adjust pot to desired LOW angle, then LONG PRESS to save. ---"); // Removed Serial.print
          }
          // Long press in Normal Mode currently has no action.
          if (storeButton.isLongPressTriggered()) {
            // Serial.println("Long press in Manual NORMAL_MODE has no action."); // Removed Serial.print
          }
          break;

        case SET_LOW_MODE:
          // Short press transitions to SET_HIGH_MODE for calibration.
          if (storeButton.isShortPressTriggered()) {
            currentManualMode = SET_HIGH_MODE;
            ledIndicator.setBlinkPattern(HIGH_MODE_ON_TIME, HIGH_MODE_OFF_TIME); // High Mode blink pattern
            // Serial.println("\n--- Entering SET_HIGH_MODE: Adjust pot to desired HIGH angle, then LONG PRESS to save. ---"); // Removed Serial.print
          }
          // Long press stores the current angle as the Low limit.
          if (storeButton.isLongPressTriggered()) {
            // Serial.print("Attempting to store LOW angle: "); // Removed Serial.print
            // Serial.print(servoCtrl.getCurrentAngle());
            // Serial.println(" degrees."); // Removed Serial.print
            posStore.storePosition(servoCtrl.getCurrentAngle(), true); // 'true' indicates setting Low
            ledIndicator.startFeedbackBlink(); // Start rapid blink feedback
            currentManualMode = NORMAL_MODE; // Return to normal mode after storing
            // Serial.println("Manual Sub-Mode: NORMAL (LED: Off, after rapid blink)"); // Removed Serial.print
          }
          break;

        case SET_HIGH_MODE:
          // Short press transitions back to NORMAL_MODE, exiting calibration.
          if (storeButton.isShortPressTriggered()) {
            currentManualMode = NORMAL_MODE;
            ledIndicator.setBlinkPattern(NORMAL_MODE_ON_TIME, NORMAL_MODE_OFF_TIME); // Set back to normal mode blink
            // Serial.println("\n--- Exiting SET_HIGH_MODE: Back to NORMAL_MODE (LED: Off). ---"); // Removed Serial.print
          }
          // Long press stores the current angle as the High limit.
          if (storeButton.isLongPressTriggered()) {
            // Serial.print("Attempting to store HIGH angle: "); // Removed Serial.print
            // Serial.print(servoCtrl.getCurrentAngle());
            // Serial.println(" degrees."); // Removed Serial.print
            posStore.storePosition(servoCtrl.getCurrentAngle(), false); // 'false' indicates setting High
            ledIndicator.startFeedbackBlink(); // Start rapid blink feedback
            currentManualMode = NORMAL_MODE; // Return to normal mode after storing
            // Serial.println("Manual Sub-Mode: NORMAL (LED: Off, after rapid blink)"); // Removed Serial.print
          }
          break;
      }
      break; // End of MANUAL_POT_CONTROL_MODE

    case MIDI_CONTROL_MODE:
      // In this mode, the servo is controlled by incoming MIDI CC#7 messages.
      // The potentiometer has no effect, and the store button is inactive.
      // The servo's position is updated by the handleControlChange() callback,
      // which is called by MIDI.read() above.
      // The LED remains off in this mode.
      // Serial.println("Current Mode: MIDI Control Mode"); // Removed Serial.print
      break; // End of MIDI_CONTROL_MODE
  }

  // Always update the LED (for blinking or solid state, and turning off blink)
  ledIndicator.update();

  // Small delay for smooth operation and readability
  delay(10);
}

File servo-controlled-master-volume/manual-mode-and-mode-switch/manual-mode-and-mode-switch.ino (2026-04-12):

#include <Servo.h>  // Include the Servo library
#include <EEPROM.h> // Include the EEPROM library for non-volatile storage

// --- Pin Definitions ---
const int POT_PIN = A0;   // Analog pin for potentiometer
const int SERVO_PIN = 9;  // Digital pin for servo control
const int BUTTON_PIN = 2; // Digital pin for the push button (using INPUT_PULLUP)

// Single LED Pin - IMPORTANT: Connect a resistor (e.g., 220-330 Ohm) in series!
const int LED_PIN = 8; // Using digital pin 8 for the single LED
const int MODE_SWITCH_PIN = 4; // Digital pin for the mode toggle switch (using INPUT_PULLUP)

// --- Constants for Mode and Button ---
const long LONG_PRESS_DURATION = 2000; // 3 seconds for a long press
const int POT_READINGS_TO_AVERAGE = 10; // Number of readings for potentiometer smoothing

// --- LED Blinking Pattern Durations (milliseconds) ---
// For SET_LOW_MODE: Short ON, Long OFF
const long LOW_MODE_ON_TIME = 100;
const long LOW_MODE_OFF_TIME = 900;

// For SET_HIGH_MODE: Short ON, Shorter OFF
const long HIGH_MODE_ON_TIME = 100;
const long HIGH_MODE_OFF_TIME = 400;

// For STORE_FEEDBACK: Very rapid flashing
const long STORE_FEEDBACK_TOGGLE_TIME = 50; // ON and OFF duration for rapid flash
const unsigned long STORE_FEEDBACK_DURATION = 500; // Total duration of the rapid flash


// --- 1. PotentiometerReader Class ---
class PotentiometerReader {
public:
  PotentiometerReader(int pin, int numReadings)
    : _pin(pin), _numReadings(numReadings), _readIndex(0), _total(0), _averagePotValue(0) {
    for (int i = 0; i < _numReadings; i++) {
      _readings[i] = 0;
    }
  }
  void update() {
    int rawPotValue = analogRead(_pin);
    _total = _total - _readings[_readIndex];
    _readings[_readIndex] = rawPotValue;
    _total = _total + _readings[_readIndex];
    _readIndex = (_readIndex + 1) % _numReadings;
    _averagePotValue = _total / _numReadings;
  }
  int getSmoothedValue() const { return _averagePotValue; }
private:
  int _pin;
  int _numReadings;
  int _readings[10];
  int _readIndex;
  long _total;
  int _averagePotValue;
  friend void setup();
};

// --- 2. ServoController Class ---
class ServoController {
public:
  ServoController(int pin, int minAngle, int maxAngle)
    : _pin(pin), _minAngle(minAngle), _maxAngle(maxAngle) {}
  void attach(int initialPotValue, int potMin, int potMax) {
    _servo.attach(_pin);
    writeMappedAngle(initialPotValue, potMin, potMax);
  }
  void writeMappedAngle(int potValue, int potMin, int potMax) {
    int targetAngle = map(potValue, potMin, potMax, _minAngle, _maxAngle);
    targetAngle = constrain(targetAngle, 0, 180);
    _servo.write(targetAngle);
    _currentAngle = targetAngle;
  }
  void writeAngle(int angle) {
    _servo.write(constrain(angle, 0, 180));
    _currentAngle = constrain(angle, 0, 180);
  }
  int getCurrentAngle() const { return _currentAngle; }
private:
  Servo _servo;
  int _pin;
  int _minAngle;
  int _maxAngle;
  int _currentAngle;
};

// --- 3. PushButton Class (Used only for the store button now) ---
class PushButton {
public:
  PushButton(int pin, long longPressDuration)
    : _pin(pin), _longPressDuration(longPressDuration),
      _lastButtonState(HIGH), _buttonPressStartTime(0), _longPressActive(false),
      _shortPressTriggered(false)
  {
    pinMode(_pin, INPUT_PULLUP);
  }
  void update() {
    int currentButtonState = digitalRead(_pin);
    if (currentButtonState != _lastButtonState) {
      _lastButtonStateChangeTime = millis();
    }
    if ((millis() - _lastButtonStateChangeTime) > _debounceDelay) {
      if (currentButtonState != _debouncedButtonState) {
        _debouncedButtonState = currentButtonState;
        if (_debouncedButtonState == LOW) {
          _buttonPressStartTime = millis();
          _longPressActive = false;
          _shortPressTriggered = false;
        } else {
          unsigned long pressDuration = millis() - _buttonPressStartTime;
          if (pressDuration >= _debounceDelay && pressDuration < _longPressDuration) {
            _shortPressTriggered = true;
          }
          _longPressActive = false;
        }
      }
    }
    _lastButtonState = currentButtonState;
    if (_debouncedButtonState == LOW &&
        (millis() - _buttonPressStartTime >= _longPressDuration) &&
        !_longPressActive) {
      _longPressActive = true;
    }
  }
  bool isLongPressTriggered() {
    if (_longPressActive) {
      _longPressActive = false;
      return true;
    }
    return false;
  }
  bool isShortPressTriggered() {
    if (_shortPressTriggered) {
      _shortPressTriggered = false;
      return true;
    }
    return false;
  }
private:
  int _pin;
  long _longPressDuration;
  int _lastButtonState;
  unsigned long _buttonPressStartTime;
  bool _longPressActive;
  bool _shortPressTriggered;
  int _debouncedButtonState = HIGH;
  unsigned long _lastButtonStateChangeTime = 0;
  const long _debounceDelay = 50;
};
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

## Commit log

2024-11-02 First Version
    [Epiphone Blues Custom 30.kicad_pcb, Epiphone Blues Custom 30.kicad_sch]
2024-11-03 Renamed Original to Schematics
    [Epiphone Blues Custom 30.kicad_pcb, Epiphone Blues Custom 30.kicad_sch]
2024-11-03 Added text to schematic
    [Epiphone Blues Custom 30.kicad_sch]
2024-11-03 Modified C3,C5,C6,C15,R15,R21
    [Epiphone Blues Custom 30.kicad_sch]
2024-11-03 Added master volume and completed sheets data
    [Epiphone Blues Custom 30.kicad_sch]
2024-11-03 changed color of master volume
    [Epiphone Blues Custom 30.kicad_sch]
2026-03-24 Changed tube types in V1, V2 and V4
    [Epiphone Blues Custom 30.kicad_sch]
2026-04-12 Bestanden weer juiste extentie gegeven
    [epiphone-blues-custom-30.kicad_pcb, epiphone-blues-custom-30.kicad_sch, servo-controlled-master-volume.kicad_sch]
2026-09-13 added partial schematics
    [gain-stage.kicad_sch, phase-inverter.kicad_sch, power-stage.kicad_sch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]
